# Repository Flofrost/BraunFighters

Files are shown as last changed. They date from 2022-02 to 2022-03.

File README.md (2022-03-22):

# GraphixCard

## Liscence

    This project is open source and open hardware, feel free too copy, edit, redistribute, and do whatever you want with it.
    I am not well versed in liscences, i just want to share my project.
    If you do use my project as a base for your work, please mention it.  :) 

## Info

    - Grahics card based on a ATMEGA1284.
    - Generates a PAL signal with 8 bit color.
    - Has a limited but expandable 3 voice synth (can add up to 3 voices).
    - Includes RS232 debugger (by that i mean it has an available RS232 port, it's up to anyone to do whatever).
    - C++ Code, compiled with avr-gcc and uploaded with avedude (using avriskmkii).
    - Electrical schematic made with Kicad.

## Objective

    - Make a funny retro video game.
    - This is the "video" part of the video game.
    - Make simple tools to program on the GraphiX Card.
    - Make a complete and handy instruction table.
    - Learn a ton about coding and electronics.

## About

    This project was brought to you by Florian Ballager, aka Flofrost.
## Braun Fighters

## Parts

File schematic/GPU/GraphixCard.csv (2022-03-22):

Id | Designator | Quantity | Designation | Supplier and ref
1 | PAL+Sound0 | 1 | AudioJack2_Ground
2 | H2,H1 | 2 | MountingHole_Pad
3 | U6,U5,U4 | 3 | 74HC04
4 | J1 | 1 | EdgeConnector-P17
5 | XPAL0 | 1 | CFPS-72
6 | GPU0 | 1 | ATmega1284-PU
7 | Q3,Q2,Q1 | 3 | 2N2222
8 | DAD0 | 1 | D
9 | U10,U9 | 2 | MCP6002-xMS
10 | RB3,RB2,RXNORPU0,RR0,RBC0,RB7,RG1,RMA4,RPDC2,RB1,RB0,RAGC1,RMV1,RPDC1,RMA3,RMA2,RMA10,RRNGPU0,RB6,RB5,RB4,RMA5,RMA0,RPDC0,RBLK0,RMA20,RMA1 | 27 | 10k
11 | RV2vol1,RV1vol1,RV0vol1 | 3 | 680
12 | RV0vol0,RV1vol0,RV2vol0 | 3 | 1k
13 | CD5,CD3,CD4,CD7,CD2,CRNGR0,CD0,CD6,CD1,CR0 | 10 | 100n
14 | RV0vol2,RV2vol2,RV1vol2 | 3 | 220
15 | RDAC0,RDAC3,RDAC2,RDAC1,RDAC6,ROC2,RDAC5,RDAC4 | 8 | 3.3k
16 | JP8,JP7,JP4,JP2,JP5,JP6,JP3,JP1 | 8 | SolderJumper_2_Open
17 | ZPAL0 | 1 | 75
18 | U7,U3 | 2 | MAX4392
19 | R2DAC2,R2DAC1,R2DAC0,R2DAC8,R2DAC7,R2DAC6,R2DAC5,R2DAC4,R2DAC3 | 9 | 6.8k
20 | RSC1,RG0 | 2 | 22k
21 | ROC0 | 1 | 100
22 | U11 | 1 | LTV-817
23 | U8 | 1 | 74HC164
24 | RPUS1,RXNOR0,RXNOR1 | 3 | 56k
25 | X0 | 1 | 20M
26 | RMV0,RMV2,RSC2,RCG3 | 4 | 10k
27 | RPUS0 | 1 | 4.7k
28 | ROC1 | 1 | 10k
29 | CE1,CAD0,CE0 | 3 | 100u
30 | RI0,RG2 | 2 | 5.6k
31 | CI0 | 1 | 470n
32 | CC2,CC1,CPUS0 | 3 | 22p
33 | AVRISPMKII0 | 1 | Conn_02x03_Counter_Clockwise
34 | RIO0 | 1 | 10k
35 | SWR0 | 1 | SW_Push
36 | U2 | 1 | 74HCT4351
37 | RPUS2 | 1 | 27k
38 | U1 | 1 | 74HC74

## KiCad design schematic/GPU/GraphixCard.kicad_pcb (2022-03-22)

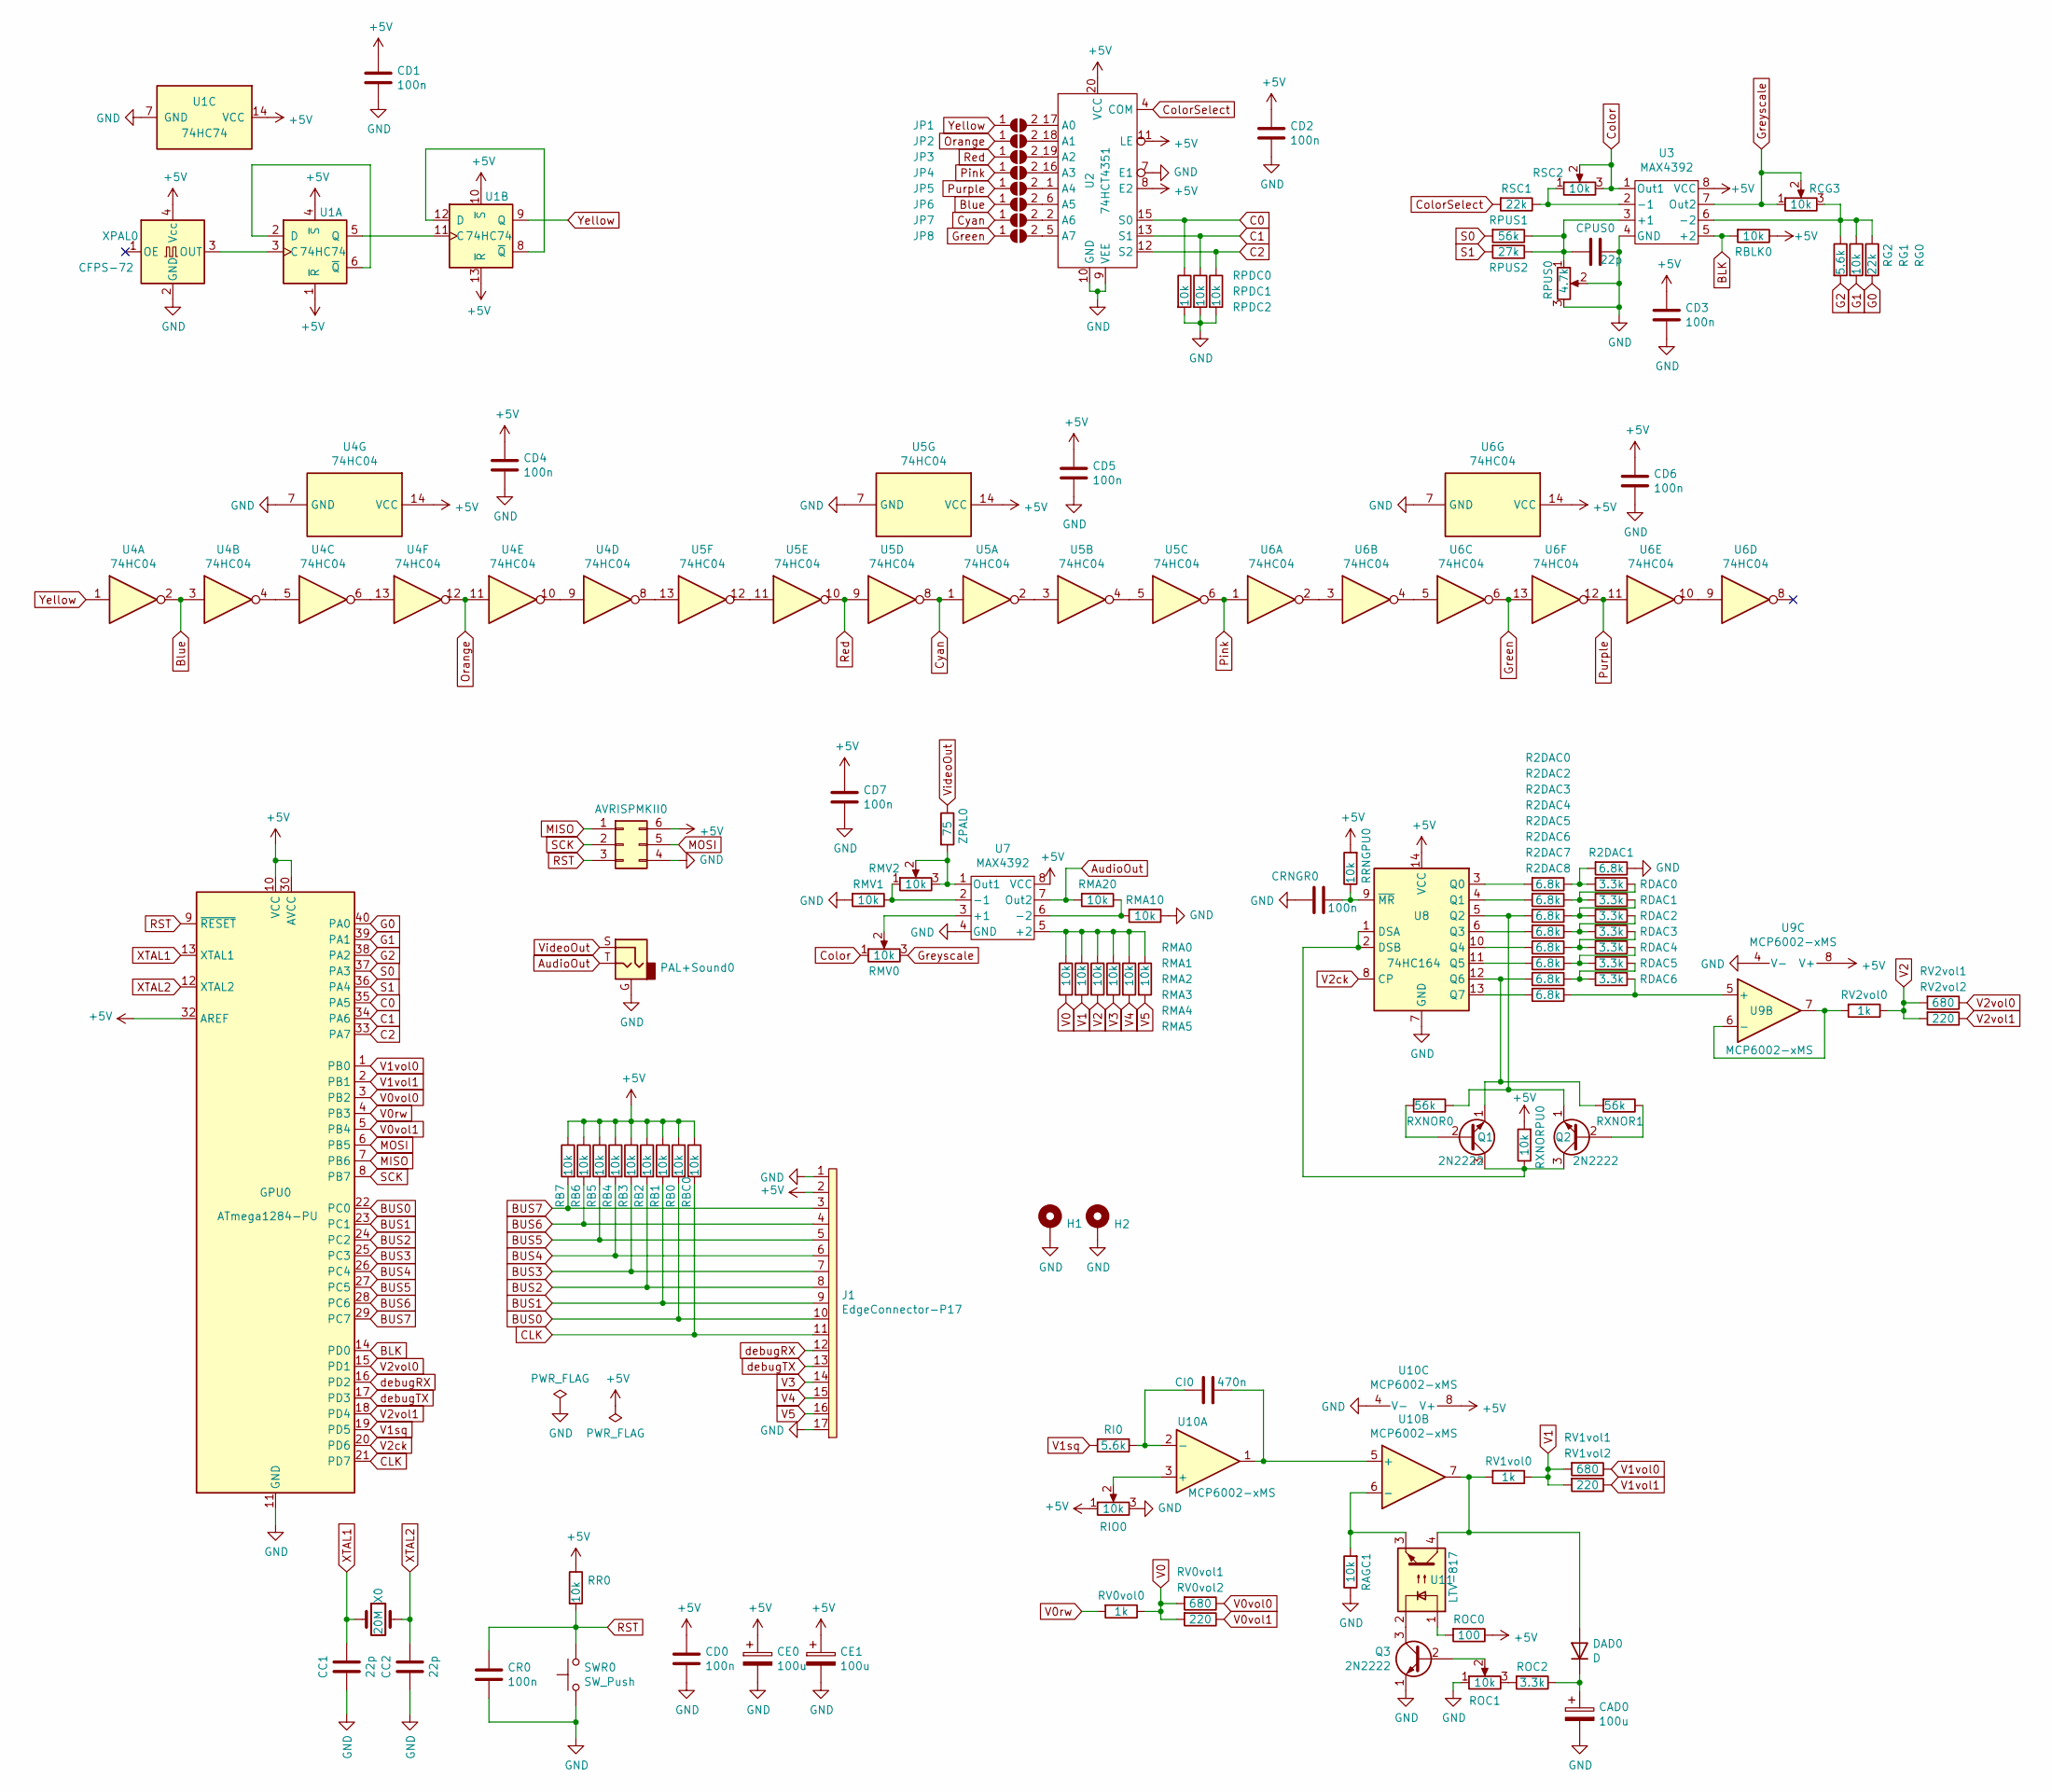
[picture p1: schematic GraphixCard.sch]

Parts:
AVRISPMKII0: Conn_02x03_Counter_Clockwise; PinSocket_2x03_P2.54mm_Vertical
CAD0: 100u; CP_Radial_D5.0mm_P2.00mm
CC1, CC2: 22p; C_Disc_D3.0mm_W1.6mm_P2.50mm
CD0, CD1, CD2, CD3, CD4, CD5, CD6, CD7: 100n; C_0805_2012Metric
CE0, CE1: 100u; CP_Radial_D5.0mm_P2.00mm
CI0: 470n; C_Rect_L7.0mm_W3.5mm_P5.00mm
CPUS0: 22p; C_Disc_D3.0mm_W1.6mm_P2.50mm
CR0: 100n; C_0805_2012Metric
CRNGR0: 100n; C_0805_2012Metric
DAD0: D; D_DO-34_SOD68_P7.62mm_Horizontal
GPU0: ATmega1284-PU; DIP-40_W15.24mm
H1, H2: MountingHole_Pad; MountingHole_3mm_Pad
J1: EdgeConnector-P17; EdgeConnector-P17-D8.00mm-P2.54mm
JP1, JP2, JP3, JP4, JP5, JP6, JP7, JP8: SolderJumper_2_Open; SolderJumper-2_P1.3mm_Open_RoundedPad1.0x1.5mm
PAL+Sound0: AudioJack2_Ground; GEII_Audio_Jack
Q1, Q2, Q3: 2N2222; SOT-23
R2DAC0, R2DAC1, R2DAC2, R2DAC3, R2DAC4, R2DAC5, R2DAC6, R2DAC7, R2DAC8: 6.8k; R_0805_2012Metric
RAGC1: 10k; R_0805_2012Metric
RB0, RB1, RB2, RB3, RB4, RB5, RB6, RB7: 10k; R_0805_2012Metric
RBC0: 10k; R_0805_2012Metric
RBLK0: 10k; R_0805_2012Metric
RCG3: 10k; Potentiometer_Piher_PT-10-V10_Vertical
RDAC0, RDAC1, RDAC2, RDAC3, RDAC4, RDAC5, RDAC6: 3.3k; R_0805_2012Metric
RG0: 22k; R_0805_2012Metric
RG1: 10k; R_0805_2012Metric
RG2: 5.6k; R_0805_2012Metric
RI0: 5.6k; R_0805_2012Metric
RIO0: 10k; Potentiometer_Vishay_T73YP_Vertical
RMA0, RMA1, RMA2, RMA3, RMA4, RMA5, RMA10, RMA20: 10k; R_0805_2012Metric
RMV0, RMV2: 10k; Potentiometer_Piher_PT-10-V10_Vertical
RMV1: 10k; R_0805_2012Metric
ROC0: 100; R_0805_2012Metric
ROC1: 10k; Potentiometer_Bourns_TC33X_Vertical
ROC2: 3.3k; R_0805_2012Metric
RPDC0, RPDC1, RPDC2: 10k; R_0805_2012Metric
RPUS0: 4.7k; Potentiometer_Piher_PT-10-V10_Vertical
RPUS1: 56k; R_0805_2012Metric
RPUS2: 27k; R_0805_2012Metric
RR0: 10k; R_0805_2012Metric
RRNGPU0: 10k; R_0805_2012Metric
RSC1: 22k; R_0805_2012Metric
RSC2: 10k; Potentiometer_Piher_PT-10-V10_Vertical
RV0vol0, RV1vol0, RV2vol0: 1k; R_0805_2012Metric
RV0vol1, RV1vol1, RV2vol1: 680; R_0805_2012Metric
RV0vol2, RV1vol2, RV2vol2: 220; R_0805_2012Metric
RXNOR0, RXNOR1: 56k; R_0805_2012Metric
RXNORPU0: 10k; R_0805_2012Metric
SWR0: SW_Push; SW_PUSH_6mm
U1: 74HC74; DIP-14_W7.62mm
U2: 74HCT4351; DIP-20_W7.62mm
U3, U7: MAX4392; OnSemi_Micro8
U4, U5, U6: 74HC04; DIP-14_W7.62mm
U8: 74HC164; DIP-14_W7.62mm
U9, U10: MCP6002-xMS; SOIC-8_3.9x4.9mm_P1.27mm
U11: LTV-817; DIP-4_W7.62mm
X0: 20M; Resonator-2Pin_W10.0mm_H5.0mm
XPAL0: CFPS-72; Oscillator_SMD_EuroQuartz_XO91-4Pin_7.0x5.0mm
ZPAL0: 75; R_0805_2012Metric

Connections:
+5V: AVRISPMKII0.6, CD0.1, CD1.1, CD2.1, CD3.1, CD4.1, CD5.1, CD6.1, CD7.1, CE0.1, CE1.1, GPU0.10 (VCC), GPU0.30 (AVCC), GPU0.32 (AREF), J1.2, RB0.1, RB1.1, RB2.1, RB3.1, RB4.1, RB5.1, RB6.1, RB7.1, RBC0.1, RBLK0.1, RIO0.1, ROC0.1, RR0.1, RRNGPU0.2, RXNORPU0.2, U1.1 (~R), U1.4 (~S), U1.10 (~S), U1.13 (~R), U1.14 (VCC), U2.8 (E2), U2.11 (LE), U2.20 (VCC), U3.8 (VCC), U4.14 (VCC), U5.14 (VCC), U6.14 (VCC), U7.8 (VCC), U8.14 (VCC), U9.8 (V+), U10.8 (V+), XPAL0.4 (Vcc)
AudioOut: PAL+Sound0.T, RMA20.2, U7.7 (Out2)
BLK: GPU0.14 (PD0), RBLK0.2, U3.5 (+2)
BUS0: GPU0.22 (PC0), J1.10, RB0.2
BUS1: GPU0.23 (PC1), J1.9, RB1.2
BUS2: GPU0.24 (PC2), J1.8, RB2.2
BUS3: GPU0.25 (PC3), J1.7, RB3.2
BUS4: GPU0.26 (PC4), J1.6, RB4.2
BUS5: GPU0.27 (PC5), J1.5, RB5.2
BUS6: GPU0.28 (PC6), J1.4, RB6.2
BUS7: GPU0.29 (PC7), J1.3, RB7.2
Blue: JP6.1 (A), U4.2, U4.3
C0: GPU0.35 (PA5), RPDC0.1, U2.15 (S0)
C1: GPU0.34 (PA6), RPDC1.1, U2.13 (S1)
C2: GPU0.33 (PA7), RPDC2.1, U2.12 (S2)
CLK: GPU0.21 (PD7), J1.11, RBC0.2
Color: RMV0.1, RSC2.2, RSC2.3, U3.1 (Out1)
ColorSelect: RSC1.2, U2.4 (COM)
Cyan: JP7.1 (A), U5.1, U5.8
G0: GPU0.40 (PA0), RG0.2
G1: GPU0.39 (PA1), RG1.2
G2: GPU0.38 (PA2), RG2.2
GND: AVRISPMKII0.4, CAD0.2, CC1.2, CC2.2, CD0.2, CD1.2, CD2.2, CD3.2, CD4.2, CD5.2, CD6.2, CD7.2, CE0.2, CE1.2, CPUS0.1, CR0.2, CRNGR0.2, GPU0.11 (GND), GPU0.31 (GND), H1.1, H2.1, J1.1, J1.17, PAL+Sound0.G, Q3.1 (E), R2DAC1.1, RAGC1.1, RIO0.3, RMA10.1, RMV1.2, ROC1.1, RPDC0.2, RPDC1.2, RPDC2.2, RPUS0.2, RPUS0.3, SWR0.1, U1.7 (GND), U2.7 (E1), U2.9 (VEE), U2.10 (GND), U3.4 (GND), U4.7 (GND), U5.7 (GND), U6.7 (GND), U7.4 (GND), U8.7 (GND), U9.4 (V-), U10.4 (V-), XPAL0.2 (GND)
Green: JP8.1 (A), U6.6, U6.13
Greyscale: RCG3.1, RCG3.2, RMV0.3, U3.7 (Out2)
MISO: AVRISPMKII0.1, GPU0.7 (PB6)
MOSI: AVRISPMKII0.5, GPU0.6 (PB5)
unnamed: CAD0.1, DAD0.1 (K), ROC2.1
unnamed: CI0.1, U10.1, U10.5 (+)
unnamed: CI0.2, RI0.1, U10.2 (-)
unnamed: CPUS0.2, RPUS0.1, RPUS1.1, RPUS2.1, U3.3 (+1)
unnamed: CRNGR0.1, RRNGPU0.1, U8.9 (~MR)
unnamed: DAD0.2 (A), RV1vol0.2, U10.7, U11.4
unnamed: JP1.2 (B), U2.17 (A0)
unnamed: JP2.2 (B), U2.18 (A1)
unnamed: JP3.2 (B), U2.19 (A2)
unnamed: JP4.2 (B), U2.16 (A3)
unnamed: JP5.2 (B), U2.1 (A4)
unnamed: JP6.2 (B), U2.6 (A5)
unnamed: JP7.2 (B), U2.2 (A6)
unnamed: JP8.2 (B), U2.5 (A7)
unnamed: Q1.1 (E), R2DAC7.2, RXNOR1.2, U8.12 (Q6)
unnamed: Q1.2 (B), RXNOR0.2
unnamed: Q1.3 (C), Q2.3 (C), RXNORPU0.1, U8.1 (DSA), U8.2 (DSB)
unnamed: Q2.1 (E), R2DAC3.2, RXNOR0.1, U8.5 (Q2)
unnamed: Q2.2 (B), RXNOR1.1
unnamed: Q3.2 (B), ROC1.2
unnamed: Q3.3 (C), U11.2
unnamed: R2DAC0.1, R2DAC1.2, RDAC0.2
unnamed: R2DAC0.2, U8.3 (Q0)
unnamed: R2DAC2.1, RDAC0.1, RDAC1.2
unnamed: R2DAC2.2, U8.4 (Q1)
unnamed: R2DAC3.1, RDAC1.1, RDAC2.2
unnamed: R2DAC4.1, RDAC2.1, RDAC3.2
unnamed: R2DAC4.2, U8.6 (Q3)
unnamed: R2DAC5.1, RDAC3.1, RDAC4.2
unnamed: R2DAC5.2, U8.10 (Q4)
unnamed: R2DAC6.1, RDAC4.1, RDAC5.2
unnamed: R2DAC6.2, U8.11 (Q5)
unnamed: R2DAC7.1, RDAC5.1, RDAC6.2
unnamed: R2DAC8.1, RDAC6.1, U9.5 (+)
unnamed: R2DAC8.2, U8.13 (Q7)
unnamed: RAGC1.2, U10.6 (-), U11.3
unnamed: RCG3.3, RG0.1, RG1.1, RG2.1, U3.6 (-2)
unnamed: RIO0.2, U10.3 (+)
unnamed: RMA0.1, RMA1.1, RMA2.1, RMA3.1, RMA4.1, RMA5.1, U7.5 (+2)
unnamed: RMA10.2, RMA20.1, U7.6 (-2)
unnamed: RMV0.2, U7.3 (+1)
unnamed: RMV1.1, RMV2.1, U7.2 (-1)
unnamed: RMV2.2, RMV2.3, U7.1 (Out1), ZPAL0.2
unnamed: ROC0.2, U11.1
unnamed: ROC1.3, ROC2.2
unnamed: RSC1.1, RSC2.1, U3.2 (-1)
unnamed: RV2vol0.2, U9.6 (-), U9.7
unnamed: U1.2 (D), U1.6 (~Q)
unnamed: U1.3 (C), XPAL0.3 (OUT)
unnamed: U1.5 (Q), U1.11 (C)
unnamed: U1.8 (~Q), U1.12 (D)
unnamed: U4.4, U4.5
unnamed: U4.8, U5.13
unnamed: U4.9, U4.10
unnamed: U4.6, U4.13
unnamed: U5.2, U5.3
unnamed: U5.4, U5.5
unnamed: U5.11, U5.12
unnamed: U6.2, U6.3
unnamed: U6.4, U6.5
unnamed: U6.9, U6.10
Orange: JP2.1 (A), U4.11, U4.12
Pink: JP4.1 (A), U5.6, U6.1
Purple: JP5.1 (A), U6.11, U6.12
RST: AVRISPMKII0.3, CR0.1, GPU0.9 (~RESET), RR0.2, SWR0.2
Red: JP3.1 (A), U5.9, U5.10
S0: GPU0.37 (PA3), RPUS1.2
S1: GPU0.36 (PA4), RPUS2.2
SCK: AVRISPMKII0.2, GPU0.8 (PB7)
V0: RMA0.2, RV0vol0.1, RV0vol1.2, RV0vol2.2
V0rw: GPU0.4 (PB3), RV0vol0.2
V0vol0: GPU0.3 (PB2), RV0vol1.1
V0vol1: GPU0.5 (PB4), RV0vol2.1
V1: RMA1.2, RV1vol0.1, RV1vol1.2, RV1vol2.2
V1sq: GPU0.19 (PD5), RI0.2
V1vol0: GPU0.1 (PB0), RV1vol1.1
V1vol1: GPU0.2 (PB1), RV1vol2.1
V2: RMA2.2, RV2vol0.1, RV2vol1.2, RV2vol2.2
V2ck: GPU0.20 (PD6), U8.8 (CP)
V2vol0: GPU0.15 (PD1), RV2vol1.1
V2vol1: GPU0.18 (PD4), RV2vol2.1
V3: J1.14, RMA3.2
V4: J1.15, RMA4.2
V5: J1.16, RMA5.2
VideoOut: PAL+Sound0.S, ZPAL0.1
XTAL1: CC1.1, GPU0.13 (XTAL1), X0.1
XTAL2: CC2.1, GPU0.12 (XTAL2), X0.2
Yellow: JP1.1 (A), U1.9 (Q), U4.1
debugRX: GPU0.16 (PD2), J1.12
debugTX: GPU0.17 (PD3), J1.13

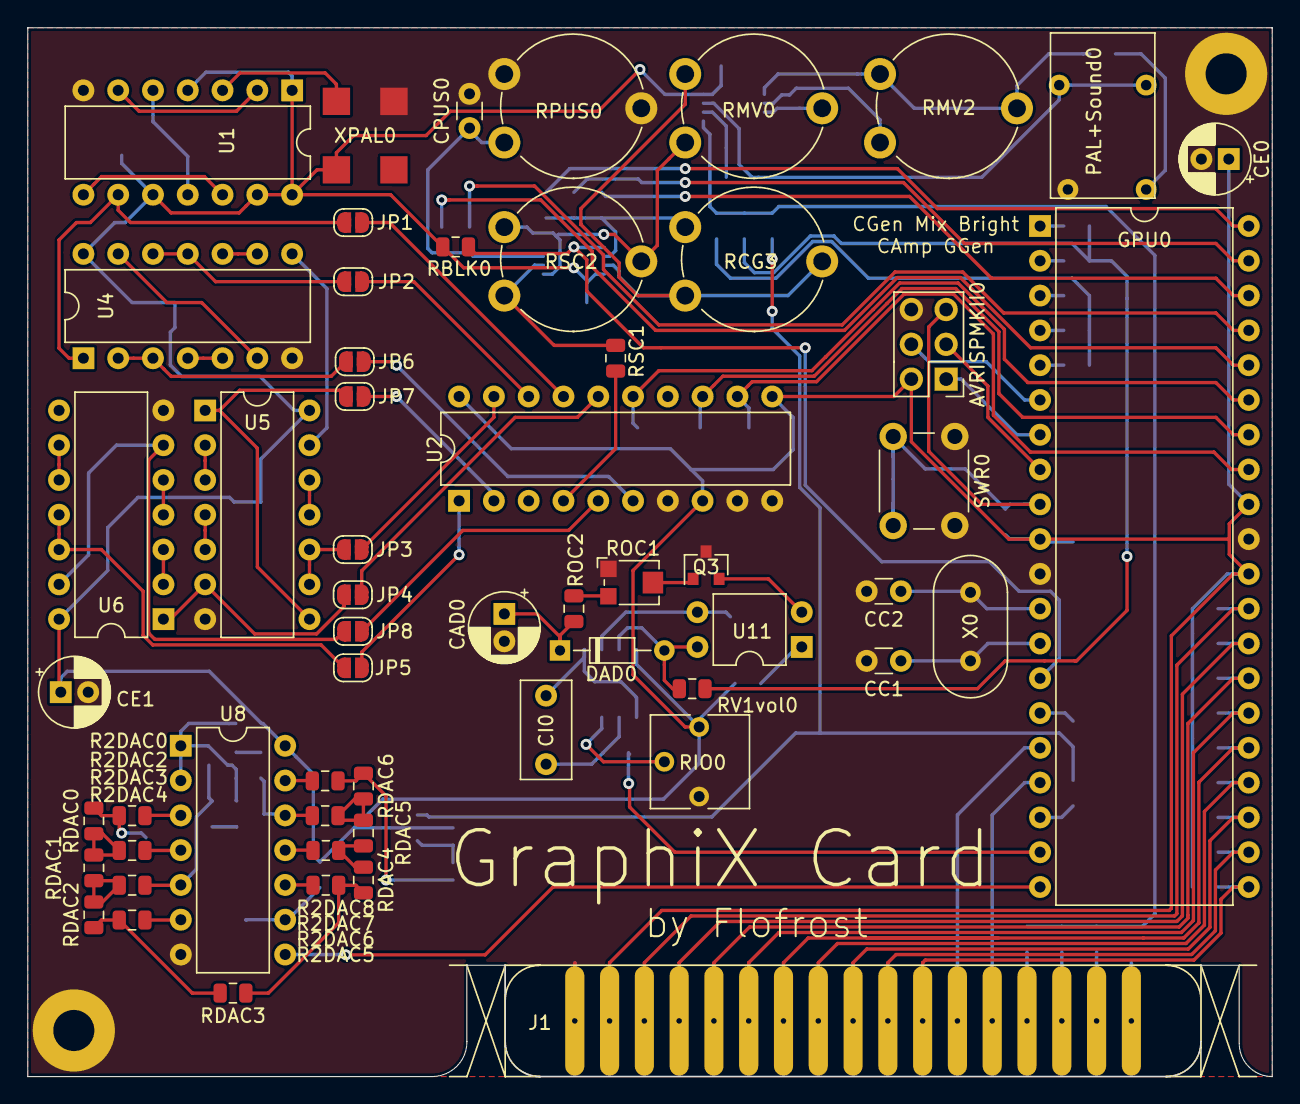
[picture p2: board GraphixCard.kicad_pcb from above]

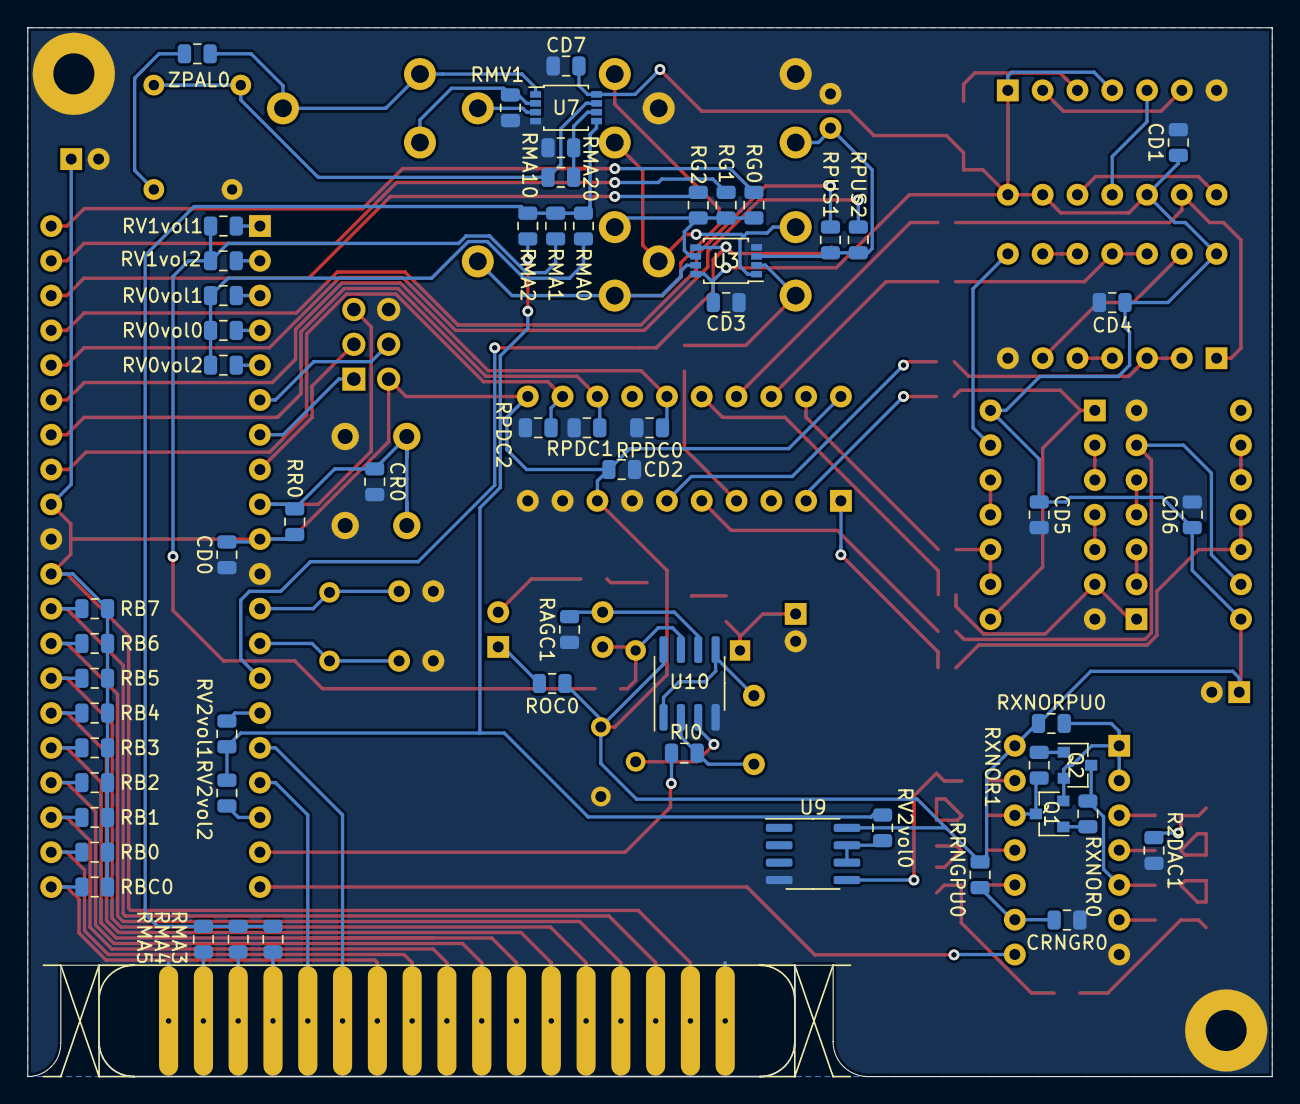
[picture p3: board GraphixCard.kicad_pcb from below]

Board: 2 copper layers, 90.9 x 76.6 mm, 119 parts (60 on the bottom side), 117 nets.

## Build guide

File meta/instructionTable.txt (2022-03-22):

Here's the available instructions with their parameters.
There's around 2800 uS available for calculus per frame.
If the sum of the time it takes to calculate the intructions exeeds 4600 uS,
it may create visual glitches, such asd chopped frames.

----------------------------------------------------------------------------------
 #  | Name          | Parameters                                     | Time (us) |
----------------------------------------------------------------------------------
 00 | fillScreen    | Color                                          | 4300      |
 01 | rShiftScreen  |                                                | 5800      |
 02 | lShiftScreen  |                                                | 5800      |
 03 | uShiftScreen  |                                                | 5900      |
 04 | dShiftScreen  |                                                | 5900      |
 05 | drawGrid      | W H Color                                      | ???? max  |
 06 | uploadScreen  |                                                | Lots of ti|*
 07 | dowloadScreen |                                                | L O N G   |
 ?? | addScreen     | Amount                                         | 6500      |
 ?? | setEnabled    | Enable                                         | 0         |
 10 | setPixel      | X Y Color                                      | 0         |
 11 | drawHLine     | Line Xstart Xend Color                         | ???? max  |
 12 | drawVLine     | Column Ystart Yend Color                       | ???? max  |
 13 | drawLine      | X1 Y1 X2 Y2 Color                              | ???? max  |
 14 | drawRect      | Xtl Ytl Xbr Ybr Color                          | ???? max  |
 15 | drawBox       | Xtl Ytl Xbr Ybr Color                          | ???? max  |
 16 | drawRPoly     | Xc Yc R E offsetAngle Color                    | ???? max  |
 17 | drawRFPoly    | Xc Yc R E offsetAngle Color                    | ???? max  |
 18 | darwPoly      | Length Color [X,Y]                             | ???? max  |
 19 | drawFPoly     | Length Color [X,Y]                             | ???? max  |
 1A | drawKinkLine  | Length Color [X,Y]                             | ???? max  |
 1B | drawCurve     | X1 Y1 X2 Y2 X3 Y3 X4 Y4 Color                  | ???? max  |*
 1C | drawChar      | X Y C Color                                    | ????      |
 1D | drawString    | X Y Color [String]                             | ???? max  |
 1E | printX        | ???                                            | ???? max  |*
 20 | drawSprite    | X Y ID Scale=0                                 | 71        |
 30 | playSquare    | Note                                           | ????      |*
 31 | playTriangle  | Note                                           | ????      |*
 31 | playNoise     | Note                                           | ????      |*
----------------------------------------------------------------------------------

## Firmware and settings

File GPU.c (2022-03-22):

#include <avr/io.h>
#include <avr/interrupt.h>
#include "src/CringeGraphics.h"
#include "src/lowMath.h"

volatile uint16_t lineCounter = 0;
volatile uint8_t done = 0, vsync = 0, can_draw = 0, enabled = 1;
volatile uint8_t line = 0, state = FPORCH, stack[256], stack_length = 0;
uint8_t frame[HEIGHT][WIDTH];

const uint8_t BURST  = 0x17;

const uint8_t BLACK  = 0xE7;
const uint8_t WHITE  = 0xE0;
const uint8_t GREY   = 0xE3;

const uint8_t YELLOW = 0x1D;
const uint8_t ORANGE = 0x3D;
const uint8_t RED    = 0x5D;
const uint8_t PINK   = 0x7D;
const uint8_t PURPLE = 0x9D;
const uint8_t BLUE   = 0xBD;
const uint8_t CYAN   = 0xDD;
const uint8_t GREEN  = 0xFD;

const uint8_t EDGE   = 0xE0;

#ifdef DEBUG
void setupDebug(){
    UBRR1L = 10;
    UCSR1C = 0x06;
    UCSR1B = 0x98;
}

void downloadScreen(uint8_t width){
    uint8_t x=0, y=0;
    stack_length = 0;
    debugSendd((uint8_t)0xE6);
    while(1){
        while(!stack_length);
        if(stack[--stack_length] == 0xE7) break;
        frame[y][x++] = stack[stack_length];
        if(x >= width){
            x = 0;
            y++;
        }
    }
}

ISR(USART1_RX_vect){
    stack[stack_length++] = UDR1;
}
#endif

#define setupTimer3()   TCCR3B = 0x0A; /* CTC + prescaler = 8 */ \
                        OCR3AL = 159;   /* f = 15625 Hz */\
                        OCR3BL = TIMING_START_DRAW_LINE;    /* begin drawing 15 uS after int */\
                        TIMSK3 = 0x06 /* compA + compB interrupt */

ISR(TIMER3_COMPA_vect){

    lineCounter++;
    if(lineCounter > 312) lineCounter = 0;
    line += lineCounter&1;
    if(lineCounter == ((HEIGHT<<1) + INCLINE - 1)){
        can_draw = 0;
        done = 0;
    }

    switch(lineCounter){
        case START_FRAME:
            line=0;
            break;

        case INCLINE:
            can_draw = enabled;
            line = 0;
            break;

        case 308:
            vsync = 1;
            break;

        case 312:
            vsync = 0;
            break;
    }

    if(!vsync){
        DDRD |= 0x01;
    }else{
        DDRD &= 0xFE;
    }

    OCR3BL = TIMING_STOP_HSYNC;
    state = FPORCH;
}

ISR(TIMER3_COMPB_vect){
    switch(state){
        case FPORCH:
            if(!vsync){
                DDRD &= 0xFE;
            }else{
                DDRD |= 0x01;
            }
            #ifndef GREYSCALE
            if(can_draw) DDRA = BURST;
            #endif
            OCR3BL = TIMING_START_DRAW_LINE;
            state = DRAW_LINE;
            break;

        case DRAW_LINE:
            if(can_draw){
                uint8_t *thisLine = frame[line];
                for(uint8_t i = 0 ; i < WIDTH ; i++){
                    DDRA = thisLine[i];
                }
            }else{
                DDRA = WHITE;
            }
            DDRA = BLACK;
            break;
    }
}

void executeStack(){
    for(uint8_t i = 0 ; i < stack_length ; i++){
        switch(stack[i]){
            case 0x00:{ //fillScreen
                fillScreen(stack[++i]);
                break;
            }
            case 0x01:{ //rShiftScreen
                rShiftScreen();
                break;
            }
            case 0x02:{ //lShiftScreen
                lShiftScreen();
                break;
            }
            case 0x03:{ //uShiftScreen
                uShiftScreen();
                break;
            }
            case 0x04:{ //dShiftScreen
                dShiftScreen();
                break;
            }
            case 0x05:{ //drawGrid
                uint8_t x = stack[++i];
                uint8_t y = stack[++i];
                drawGrid(x,y,stack[++i]);
                break;
            }
            #ifdef DEBUG
            case 0x06:{ //downloadScreen
                downloadScreen(stack[++i]);
                stack_length = 0;
                break;
            }
            #endif
            case 0x10:{ //setPixel
                const uint8_t x = stack[++i];
                const uint8_t y = stack[++i];
                setPixel(x,y,stack[++i]);
                break;
            }
            case 0x11:{ //drawHLine
                const uint8_t h = stack[++i];
                const uint8_t s = stack[++i];
                const uint8_t e = stack[++i];
                drawHLine(h,s,e,stack[++i]);
                break;
            }
            case 0x12:{ //drawVLine
                const uint8_t l = stack[++i];
                const uint8_t s = stack[++i];
                const uint8_t e = stack[++i];
                drawVLine(l,s,e,stack[++i]);
                break;                
            }
            case 0x13:{ //drawLine
                const uint8_t x1 = stack[++i];
                const uint8_t y1 = stack[++i];
                const uint8_t x2 = stack[++i];
                const uint8_t y2 = stack[++i];
                drawLine(x1,y1,x2,y2,stack[++i]);
                break;                
            }
            case 0x14:{ //drawRect
                const uint8_t x1 = stack[++i];
                const uint8_t y1 = stack[++i];
                const uint8_t x2 = stack[++i];
                const uint8_t y2 = stack[++i];
                drawRect(x1,y1,x2,y2,stack[++i]);
                break;
            }
            case 0x15:{ //drawFRect
                const uint8_t x1 = stack[++i];
                const uint8_t y1 = stack[++i];
                const uint8_t x2 = stack[++i];
                const uint8_t y2 = stack[++i];
                drawFRect(x1,y1,x2,y2,stack[++i]);
                break;
            }
            case 0x16:{ //drawRPoly
                const uint8_t xc = stack[++i];
                const uint8_t yc = stack[++i];
                const uint8_t r = stack[++i];
                const uint8_t e = stack[++i];
                const uint8_t ao = stack[++i];
                drawRPoly(xc,yc,r,e,ao,stack[++i]);
                break;
            }
            case 0x17:{ //drawRFPoly
                const uint8_t xc = stack[++i];
                const uint8_t yc = stack[++i];
                const uint8_t r = stack[++i];
                const uint8_t e = stack[++i];
                const uint8_t ao = stack[++i];
                drawRFPoly(xc,yc,r,e,ao,stack[++i]);
                break;
            }
            case 0x18:{ //drawPoly
                const uint8_t l = stack[++i];
                const uint8_t c = stack[++i];
                drawPoly(l,c,(const uint8_t*)&stack[++i]);
                i += l<<1;
                break;
            }
            case 0x19:{ //drawFPoly
                const uint8_t l = stack[++i];
                const uint8_t c = stack[++i];
                drawFPoly(l,c,(const uint8_t*)&stack[++i]);
                i += l<<1;
                break;
            }
            case 0x1A:{ //drawKinkLine
                const uint8_t l = stack[++i];
                const uint8_t c = stack[++i];
                drawKinkLine(l,c,(const uint8_t*)&stack[++i]);
                i += l<<1;
                break;
            }
            case 0x1C:{ //drawChar
                const uint8_t x = stack[++i];
                const uint8_t y = stack[++i];
                const uint8_t c = stack[++i];
                drawChar(x,y,c,stack[++i]);
                break;
            }
            case 0x1D:{ //drawString
                const uint8_t x = stack[++i];
                const uint8_t y = stack[++i];
                const uint8_t c = stack[++i];
                i += drawString(x,y,(char *)&stack[++i],c);
                break;
            }
            case 0x30:{ //changeVoice0
                changeVoice0(stack[++i]);
                break;
            }
            case 0x31:{ //changeVoice1
                changeVoice1(stack[++i]);
                break;
            }
            case 0x32:{ //changeVoice2
                changeVoice2(stack[++i]);
                break;
            }
            #ifdef DEBUG
            default:{ //Error MSG
                debugSendd((const uint8_t)0xEE);
                stack_length = 0;
            }
            #endif
        }
    }
    stack_length = 0;
}

int main(){
    for(uint8_t l = 0; l < HEIGHT ; l++)
        for(uint8_t i = 0 ; i < WIDTH ; i++)
            frame[l][i] = l+i;

    MCUCR |= (1<<PUD); //Disable pullup resistors

    setupTimer3();
    setupVoice2();  //setup timer and voices
    setupVoice1();
    setupVoice0();

    PORTA = 0xFF;

    sei();

    #ifdef DEBUG
    setupDebug();
    debugSends((char*)"RRR");
    #endif


    // fetchStack();
    // debugSendd(stack_length);
    // for(uint8_t i = 0 ; i < stack_length ; i++) debugSendd(stack[i]);
    //executeStack();

    processShit:
    if(CAN_CALCULATE){
    }

    done = 1;
    while(done);
    goto processShit;

    return 0;
}

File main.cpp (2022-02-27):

#include <avr/io.h>
#include <avr/interrupt.h>
#include "sources/SynthX.h"

#define clkF() DDRD |= 0x80
#define clkR() DDRD &= 0x7F
#define CLK  (PIND & 0x80)
#define BUSW  DDRC
#define BUSR  PINC

volatile uint8_t stack[256] = {0x50,0x51,0x52,0x53}, stackLength = 4;

ISR(PCINT3_vect){
    cli();

    sei();
}

int main(){

    PCICR = 0x08;
    PCMSK3 = 0x80; //set CLK as PCINT

    sei();

    while(1){

    }

    return 0;
}

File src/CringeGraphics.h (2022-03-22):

#ifndef CRINGEGRAPHICS_H
#define CRINGEGRAPHICS_H   

#include <avr/pgmspace.h>

//#define GREYSCALE

#define WIDTH 120
#define HEIGHT 120
#define TOTALPIXELS 14400
#define START_FRAME 28
#define INCLINE 40

#define FPORCH 0
#define START_BURST 1
#define STOP_BURST 2
#define DRAW_LINE 3

#define TIMING_STOP_HSYNC 15
#define TIMING_START_DRAW_LINE 40

#define clkF() DDRD |= 0x80
#define clkR() DDRD &= 0x7F
#define CLK  (PIND & 0x80)
#define BUSR     PINC
#define BUSW(x)  DDRC = ~(x)


extern volatile uint16_t lineCounter;
extern volatile uint8_t done, vsync, can_draw, enabled;
extern volatile uint8_t line, state, stack[256], stack_length;
extern uint8_t frame[HEIGHT][WIDTH];

extern const uint8_t BURST;

extern const uint8_t BLACK;
extern const uint8_t WHITE;
extern const uint8_t GREY;

extern const uint8_t YELLOW;
extern const uint8_t ORANGE;
extern const uint8_t RED;
extern const uint8_t PINK;
extern const uint8_t PURPLE;
extern const uint8_t BLUE;
extern const uint8_t CYAN;
extern const uint8_t GREEN;

extern const uint8_t EDGE;


#ifdef DEBUG
#include <stdio.h>
void debugSendd(const uint8_t x);
void debugSends(const char* s);
#endif

#define CAN_CALCULATE (!can_draw)

//Asks CPU for stack
void fetchStack();

//enables display, disabling display yields display time to calculations
void setEnabled(const uint8_t ena);
//Fills the whole screen with a color.
void fillScreen(const uint8_t color);
//Adds a value to each pixel.
void addScreen(const char amount);
//Shifts the whole screen to the right by an amount.
void rShiftScreen();
//Shifts the whole screen to the left by an amount.
void lShiftScreen();
//Shifts the whole screen upwards by an amount.
void uShiftScreen();
//Shifts the whole screen downwards by an amount.
void dShiftScreen();
//Draws an orthonormal grid across the screen
void drawGrid(const uint8_t x, const uint8_t y, const uint8_t color);
//Changes a single pixel
void setPixel(const uint8_t x, const uint8_t y, const uint8_t color);
//Draws a horizontal line.
void drawHLine(const uint8_t line, const uint8_t start, const uint8_t end, const uint8_t color);
//Draws a vertical line.
void drawVLine(const uint8_t column, const uint8_t start, const uint8_t end, const uint8_t color);
//Draw any line.
void drawLine(const uint8_t x1, const uint8_t y1, const uint8_t x2, const uint8_t y2, const uint8_t color);
//Draws a hollow rectangle.
void drawRect(const uint8_t xs, const uint8_t ys, const uint8_t xe, const uint8_t ye, const uint8_t color);
//Draws a filled rectangle.
void drawFRect(const uint8_t xs, const uint8_t ys, const uint8_t xe, const uint8_t ye, const uint8_t color);
//Draws a regular polygon
void drawRPoly(const uint8_t xc, const uint8_t yc, const uint8_t radius, const uint8_t edges, const uint8_t angleOffset, const uint8_t color);
//Draws a filled regular polygon
void drawRFPoly(const uint8_t xc, const uint8_t yc, const uint8_t radius, const uint8_t edges, const uint8_t angleOffset, const uint8_t color);
//Draws a polygon following the points given
void drawPoly(const uint8_t edges, const uint8_t color, const uint8_t* points);
//Draws a filled polygon following the points given
void drawFPoly(const uint8_t edges, const uint8_t color, const uint8_t* points);
//Draws a segmented line, points are structured as follow: [x0,y0,x1,y1,x2,y2,x3,y3,x4,y4...]
void drawKinkLine(const uint8_t length, const uint8_t color, const uint8_t* points);
//Draws a character
void drawChar(const uint8_t x, const uint8_t y, const char c, const uint8_t color);
//Draws a string of characters, returns length of printed string
uint8_t drawString(const uint8_t xs, const uint8_t ys, const char* s, const uint8_t color);
//Draws a sprite
void drawSprite(const uint8_t x, const uint8_t y, const uint8_t spritID, const uint8_t options);

//Colors inside a shape using the edge fake color
void colorIn(const uint8_t x1, const uint8_t y1, const uint8_t x2, const uint8_t y2, const uint8_t color);


#define guess_prescaler0(note) (((note) < 15) ? 5 :(\
                               ((note) < 39) ? 4 : 3))

#define guess_prescaler2(note) (((note) < 15) ? 7 :(\
                               ((note) < 27) ? 6 :(\
                               ((note) < 39) ? 5 : 4)))

#define setupVoice0()   TCCR0A = 0x42;\
                        DDRB |= 1<<PB3

void changeVoice0(const uint8_t tone);

#define setupVoice1()   TCCR1A = 0x40;\
                        TCCR1B = 0x08;\
                        DDRD |= 1<<PD5

void changeVoice1(const uint8_t tone);

#define setupVoice2()   TCCR2A = 0x12;\
                        DDRD |= (1<<PD6)

void changeVoice2(const uint8_t tone);


#endif

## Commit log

2021-12-23 Communication Protocol reset, need to rethink it
    [main.cpp]
2022-03-22 Fused repo with CringeGraphics (formerly GraphiX)
    [GraphixCard-B_Cu.gbl, GraphixCard-B_Mask.gbs, GraphixCard-B_SilkS.gbo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]
